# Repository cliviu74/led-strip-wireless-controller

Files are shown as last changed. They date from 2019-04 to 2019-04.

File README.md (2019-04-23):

# LED strip wireless controller
## Design Goals
- inexpensive (don't like to say cheap :) )
- readily available parts
- low power consumption when idle
- reliable, this will be powered on 24x7
- MQTT controllable, I use [Home Assistant](https://github.com/home-assistant/home-assistant) for my home automation needs
- easy upgradable firmware. [Sonoff-Tasmota](https://github.com/arendst/Sonoff-Tasmota) is brilliant for this, very active project, supports OTA updates.

## Shopping list, bill of materials
- wemos d1 mini board, [Aliexpress](https://www.aliexpress.com/item/D1-mini-Mini-NodeMcu-4M-bytes-Lua-WIFI-Internet-of-Things-development-board-based-ESP8266-by/32631693796.html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,searchweb201602_9_10065_10068_319_10059_10884_317_10887_10696_321_322_10084_453_10083_454_10103_10618_10304_10307_10820_10821_537_10302_536,searchweb201603_80,ppcSwitch_0&algo_expid=1861050a-e1ad-4a70-8436-a3a60d32f714-0&algo_pvid=1861050a-e1ad-4a70-8436-a3a60d32f714&transAbTest=ae803_4), € 1,81
- 12V step down/buck convertor to 5V, [Aliexpress](https://www.aliexpress.com/item/1PCS-High-Quality-3A-Adjustable-DCDC-LM2596-LM2596S-input-4V-35V-Output-1-23V-30V-dc/32280431843.html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,searchweb201602_9_10065_10068_319_10059_10884_317_10887_10696_321_322_10084_453_10083_454_10103_10618_10304_10307_10820_10821_537_10302_536,searchweb201603_80,ppcSwitch_0&algo_expid=9a5396ae-bf58-4f48-870a-80717f2fafc6-0&algo_pvid=9a5396ae-bf58-4f48-870a-80717f2fafc6&transAbTest=ae803_4), € 0,55
- 12V/3A power supply, [Aliexpress](https://www.aliexpress.com/item/DC12V3A-Power-Adapter-for-Led-Strip-DC12V36W-Voltage-Transfomer-with-UK-Plug-Power-Supply-Led-Driver/32815451511.html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,searchweb201602_9_10065_10068_319_10059_10884_317_10887_10696_321_322_10084_453_10083_454_10103_10618_10304_10307_10820_10821_537_10302_536,searchweb201603_80,ppcSwitch_0&algo_expid=6a58a83f-3606-464d-81c6-f886531599b0-2&algo_pvid=6a58a83f-3606-464d-81c6-f886531599b0&transAbTest=ae803_4), € 6,50
- 2x Female Barrel Power jack, [Aliexpress](https://www.aliexpress.com/item/5-PCS-Lot-Power-Plug-Adaptors-Pigtail-Female-Barrel-Jack-Wire-Cable-5-5mm-x-2/32904315691.html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,searchweb201602_9_10065_10068_319_10059_10884_317_10887_10696_321_322_10084_453_10083_454_10103_10618_10304_10307_10820_10821_537_10302_536,searchweb201603_80,ppcSwitch_0&algo_expid=37d5a2b8-4379-4891-827b-75b46672e7a3-22&algo_pvid=37d5a2b8-4379-4891-827b-75b46672e7a3&transAbTest=ae803_4), € 3,16 for a pack of five
- 2.2K resistor, [Aliexpress](https://www.aliexpress.com/item/New-300pcs-1-4W-1-Metal-film-resistor-510-560-1K-1-1K-1-2K-ohm/32821605455.html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,searchweb201602_9_10065_10068_319_10059_10884_317_10887_10696_321_322_10084_453_10083_454_10103_10618_10304_10307_10820_10821_537_10302_536,searchweb201603_80,ppcSwitch_0&algo_expid=58aaaa6b-7571-4ac8-ab41-2110da4f70e3-1&algo_pvid=58aaaa6b-7571-4ac8-ab41-2110da4f70e3&transAbTest=ae803_4), € 0,51 for a pack of 100. Probably better to get a mixed pack of resistors as it may be more useful to have a variety of values rather then 100 pcs of the same value.
- relay board, [Aliexpress](https://www.aliexpress.com/item/with-optical-coupler-1-way-relay-module-relay-expansion-board-high-and-low-level-trigger-all/32810054219.html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,searchweb201602_9_10065_10068_319_10059_10884_317_10887_10696_321_322_10084_453_10083_454_10103_10618_10304_10307_10820_10821_537_10302_536,searchweb201603_80,ppcSwitch_0&algo_expid=90567901-fe45-484e-a215-4ade06886cad-1&algo_pvid=90567901-fe45-484e-a215-4ade06886cad&transAbTest=ae803_4), € 1,97
- some prototype board to place components on, not necessarily required but keeps things tidy. You may buy a bunch for € 1.15 on [Aliexpress](https://www.aliexpress.com/item/86036-Free-shipping-10pcs-Double-Side-Prototype-PCB-diy-Universal-Printed-Circuit-Board-4x6cm/32656277833.html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,searchweb201602_9_10065_10068_319_10059_10884_317_10887_10696_321_322_10084_453_10083_454_10103_10618_10304_10307_10820_10821_537_10302_536,searchweb201603_80,ppcSwitch_0&algo_expid=e080477f-abf9-488f-a106-1877b4097355-1&algo_pvid=e080477f-abf9-488f-a106-1877b4097355&transAbTest=ae803_4)
- project box, to pack things neatly, had one lying around from another project, but you can get one on [Aliexpress](https://www.aliexpress.com/item/100x60x25mm-Waterproof-Black-DIY-Housing-Instrument-Case-Plastic-Electronic-Project-Box-Electric-Supplies/32952374406.html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,searchweb201602_9_10065_10068_319_10059_10884_317_10887_10696_321_322_10084_453_10083_454_10103_10618_10304_10307_10820_10821_537_10302_536,searchweb201603_80,ppcSwitch_0&algo_expid=e4a25903-b728-4dbb-816b-787c5d968988-0&algo_pvid=e4a25903-b728-4dbb-816b-787c5d968988&transAbTest=ae803_4), € 1,17. Check for size as you need to fit all the boards plus wires. 
- some wire, always have a good stock of wires around the place so it didn't cost me a penny. 
## Tools
- soldering iron, you can get away without one if you're using prototyping wire, but I went for soldering as wanted to make this as reliable as possible.
- wire clippers, screwdrivers, 
- solder
- laptop for programming the board (goes without saying you have one handy, since I hope you're not reading this page on paper :) )
- software for the initial firmware upload to the wemos board. I personally use [Esptool](https://github.com/arendst/Sonoff-Tasmota/wiki/Esptool) or [VSCode](https://code.visualstudio.com/) with the [PlatformIO plugin](https://docs.platformio.org/en/latest/ide/vscode.html). You can also use [Arduino IDE](https://www.arduino.cc/en/main/software)

## Schematic
Fritzing schematic can be downloaded and edited in this repo [Friting schematic](schematic/led-strip-wireless-controller.fzz)

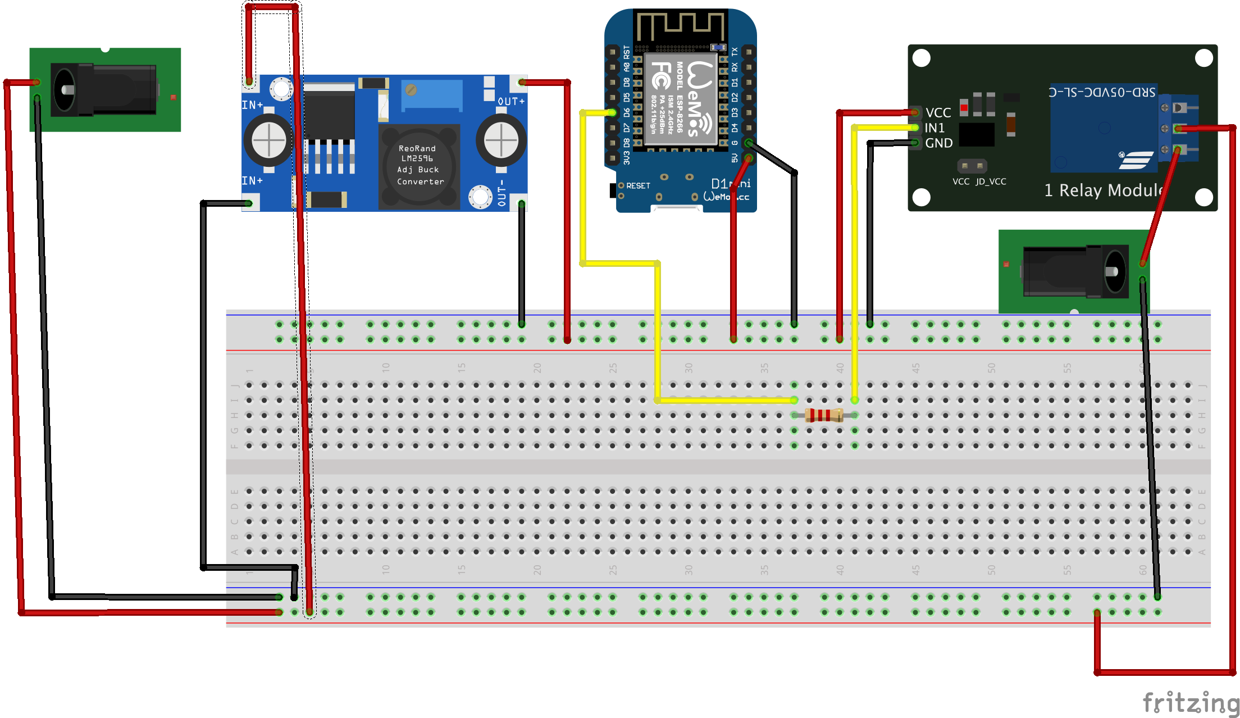
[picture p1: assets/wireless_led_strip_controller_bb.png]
Schematic


## Firmware installation 

I've used Esptool for this upload, so I will cover this procedure in this document. Tasmota has covered firmware upload using different tools extensively. 

```
✗ curl -L https://github.com/arendst/Sonoff-Tasmota/releases/download/v6.5.0/sonoff.bin -o sonoff.bin
  % Total    % Received % Xferd  Average Speed   Time    Time     Time  Current
                                 Dload  Upload   Total   Spent    Left  Speed
100   600    0   600    0     0   1127      0 --:--:-- --:--:-- --:--:--  1129
100  507k  100  507k    0     0   208k      0  0:00:02  0:00:02 --:--:--  348k
✗ esptool.py --port /dev/tty.wchusbserial1420 erase_flash
✗ esptool.py --port /dev/tty.wchusbserial1420 write_flash -fs 1MB -fm dout 0x0 firmware/sonoff.bin
```
## End result
Once tested on a breadbord, I started soldering evering and tucked all boards neatly in a project box, using some hot glue. The end result is here:
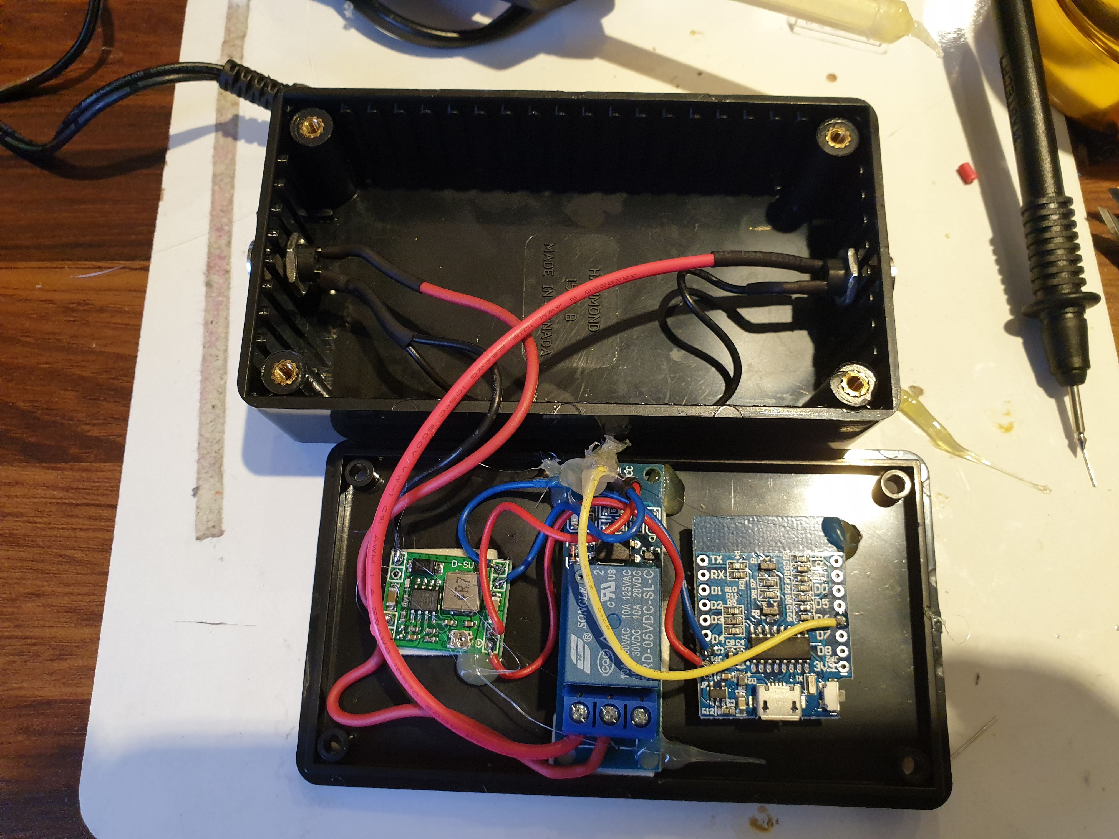
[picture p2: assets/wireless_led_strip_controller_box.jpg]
Project Box


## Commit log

2019-04-13 Added fritzing schematic
    [led-strip-wireless-controller.fzz]
2019-04-13 Schematic image export
